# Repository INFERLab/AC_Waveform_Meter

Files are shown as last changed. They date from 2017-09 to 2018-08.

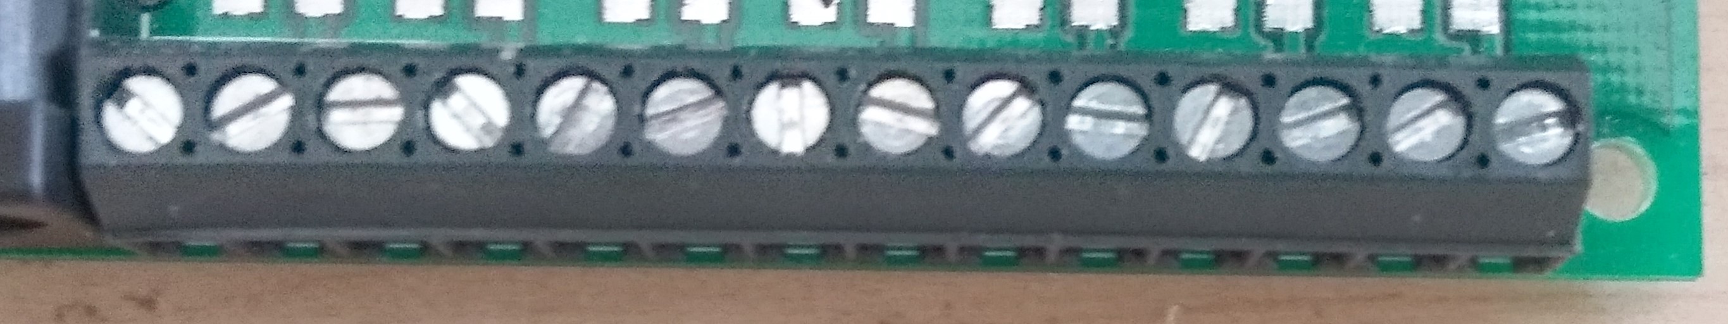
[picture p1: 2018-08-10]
images/Documentation Pictures/IMAG1642.jpg

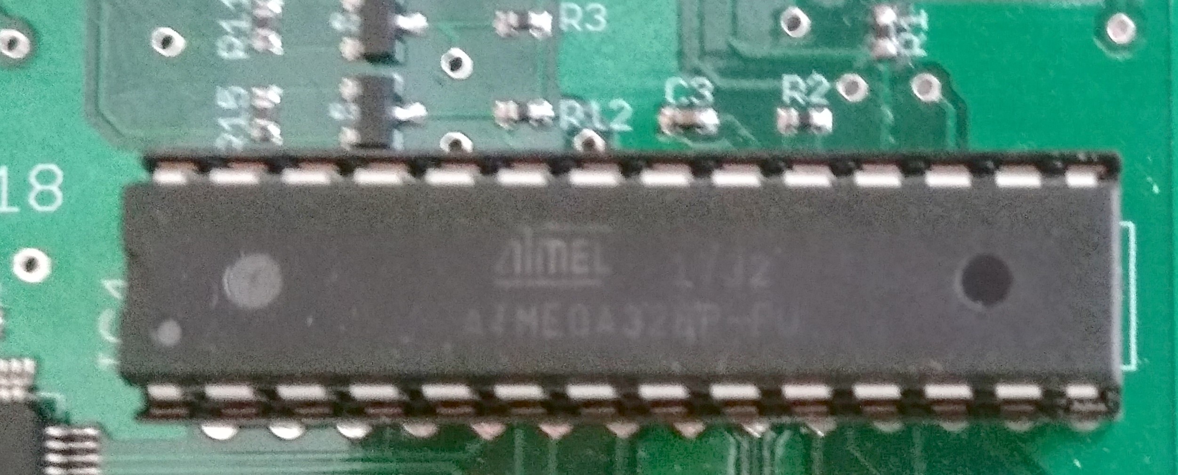
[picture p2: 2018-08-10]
images/Documentation Pictures/IMAG1639.jpg

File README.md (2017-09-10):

# AC Waveform Meter 
Arduino-based Open-source AC Waveform meter in a shield form factor for the Raspberry Pi 3. This low-cost AC power meter is designed to continuously measure voltage and current waveforms at up to 14 kHz.

## Repository Contents
- **/hardware** - All Eagle designs files (.brd, .sch)
- **/src** - Source files for the power meter and Raspberry Pi 3
- **/extras** - Additional documentation for the power meter
- **/examples** - Example sketches for the power meter in .ino (run these from the Arduino IDE) and .c

## Wiki
Set up details for the micro controller firmware and the Raspberry Pi 3.

## Version History
- V1.0 - Initial Release

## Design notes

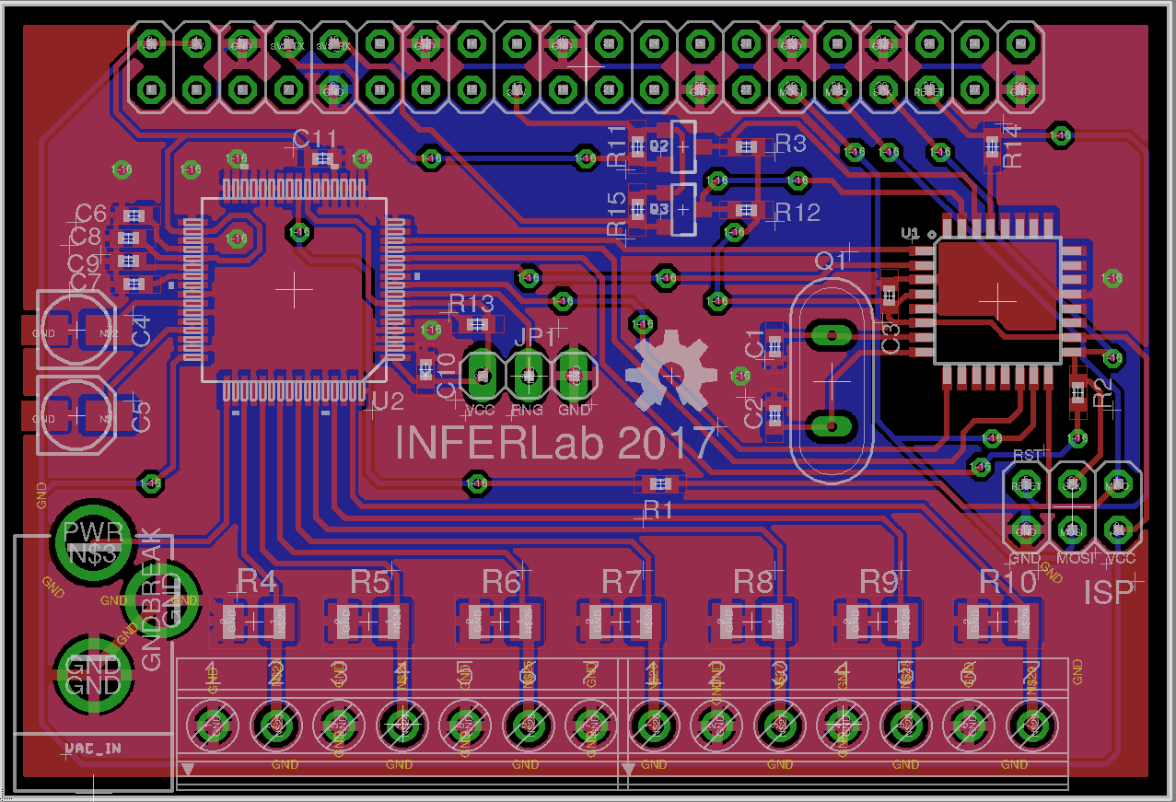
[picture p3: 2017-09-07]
hardware/EaglePCB.png

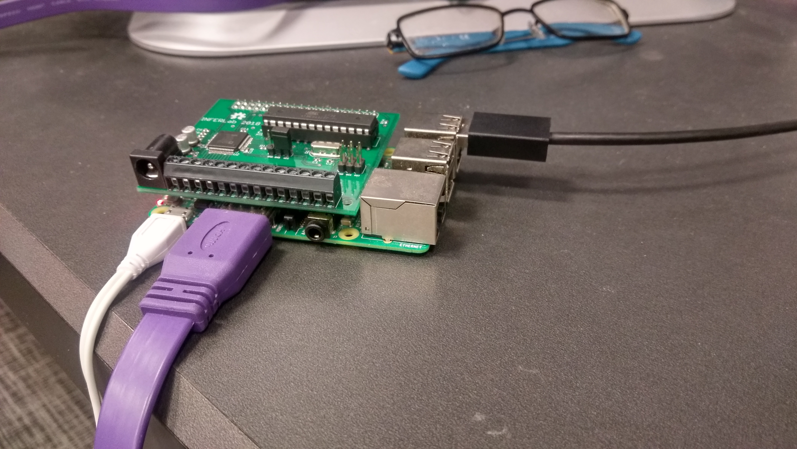
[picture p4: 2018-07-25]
images/Documentation Pictures/IMAG1631.jpg

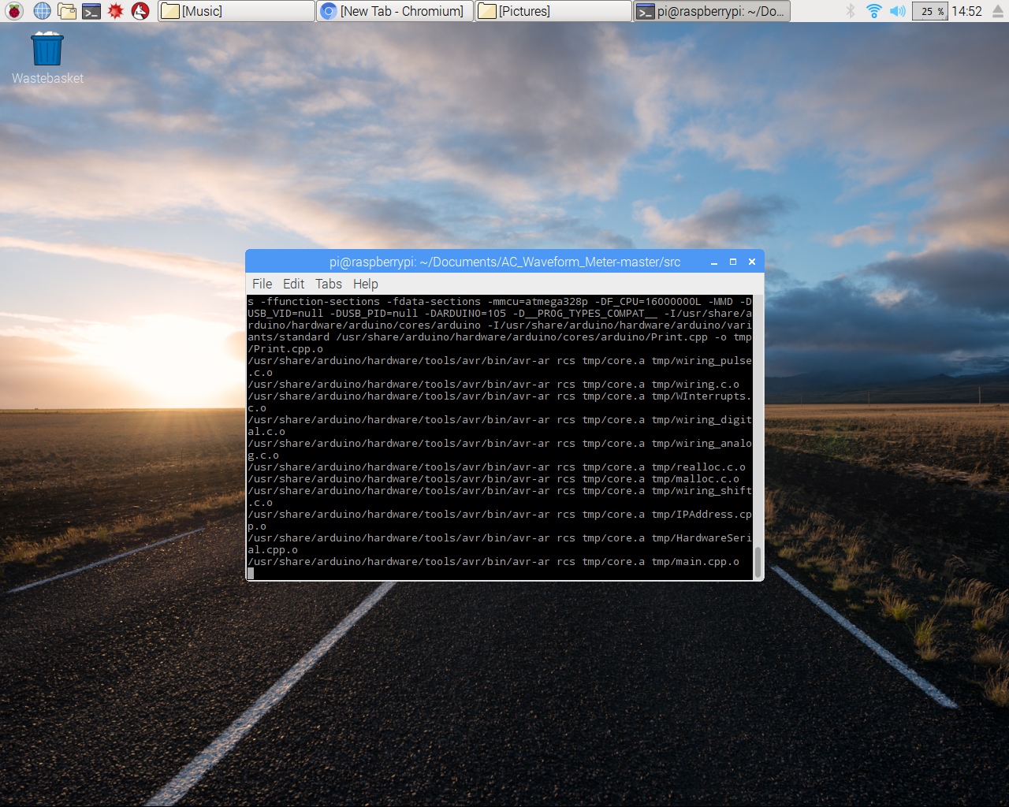
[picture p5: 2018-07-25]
images/Documentation Pictures/2018-07-11-145228_1280x1024_scrot.png

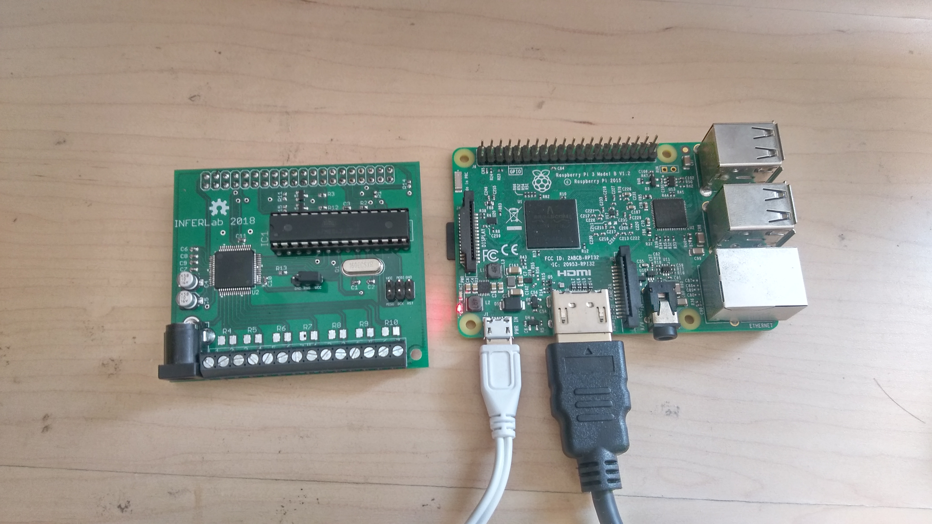
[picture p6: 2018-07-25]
images/Documentation Pictures/IMAG1637.jpg

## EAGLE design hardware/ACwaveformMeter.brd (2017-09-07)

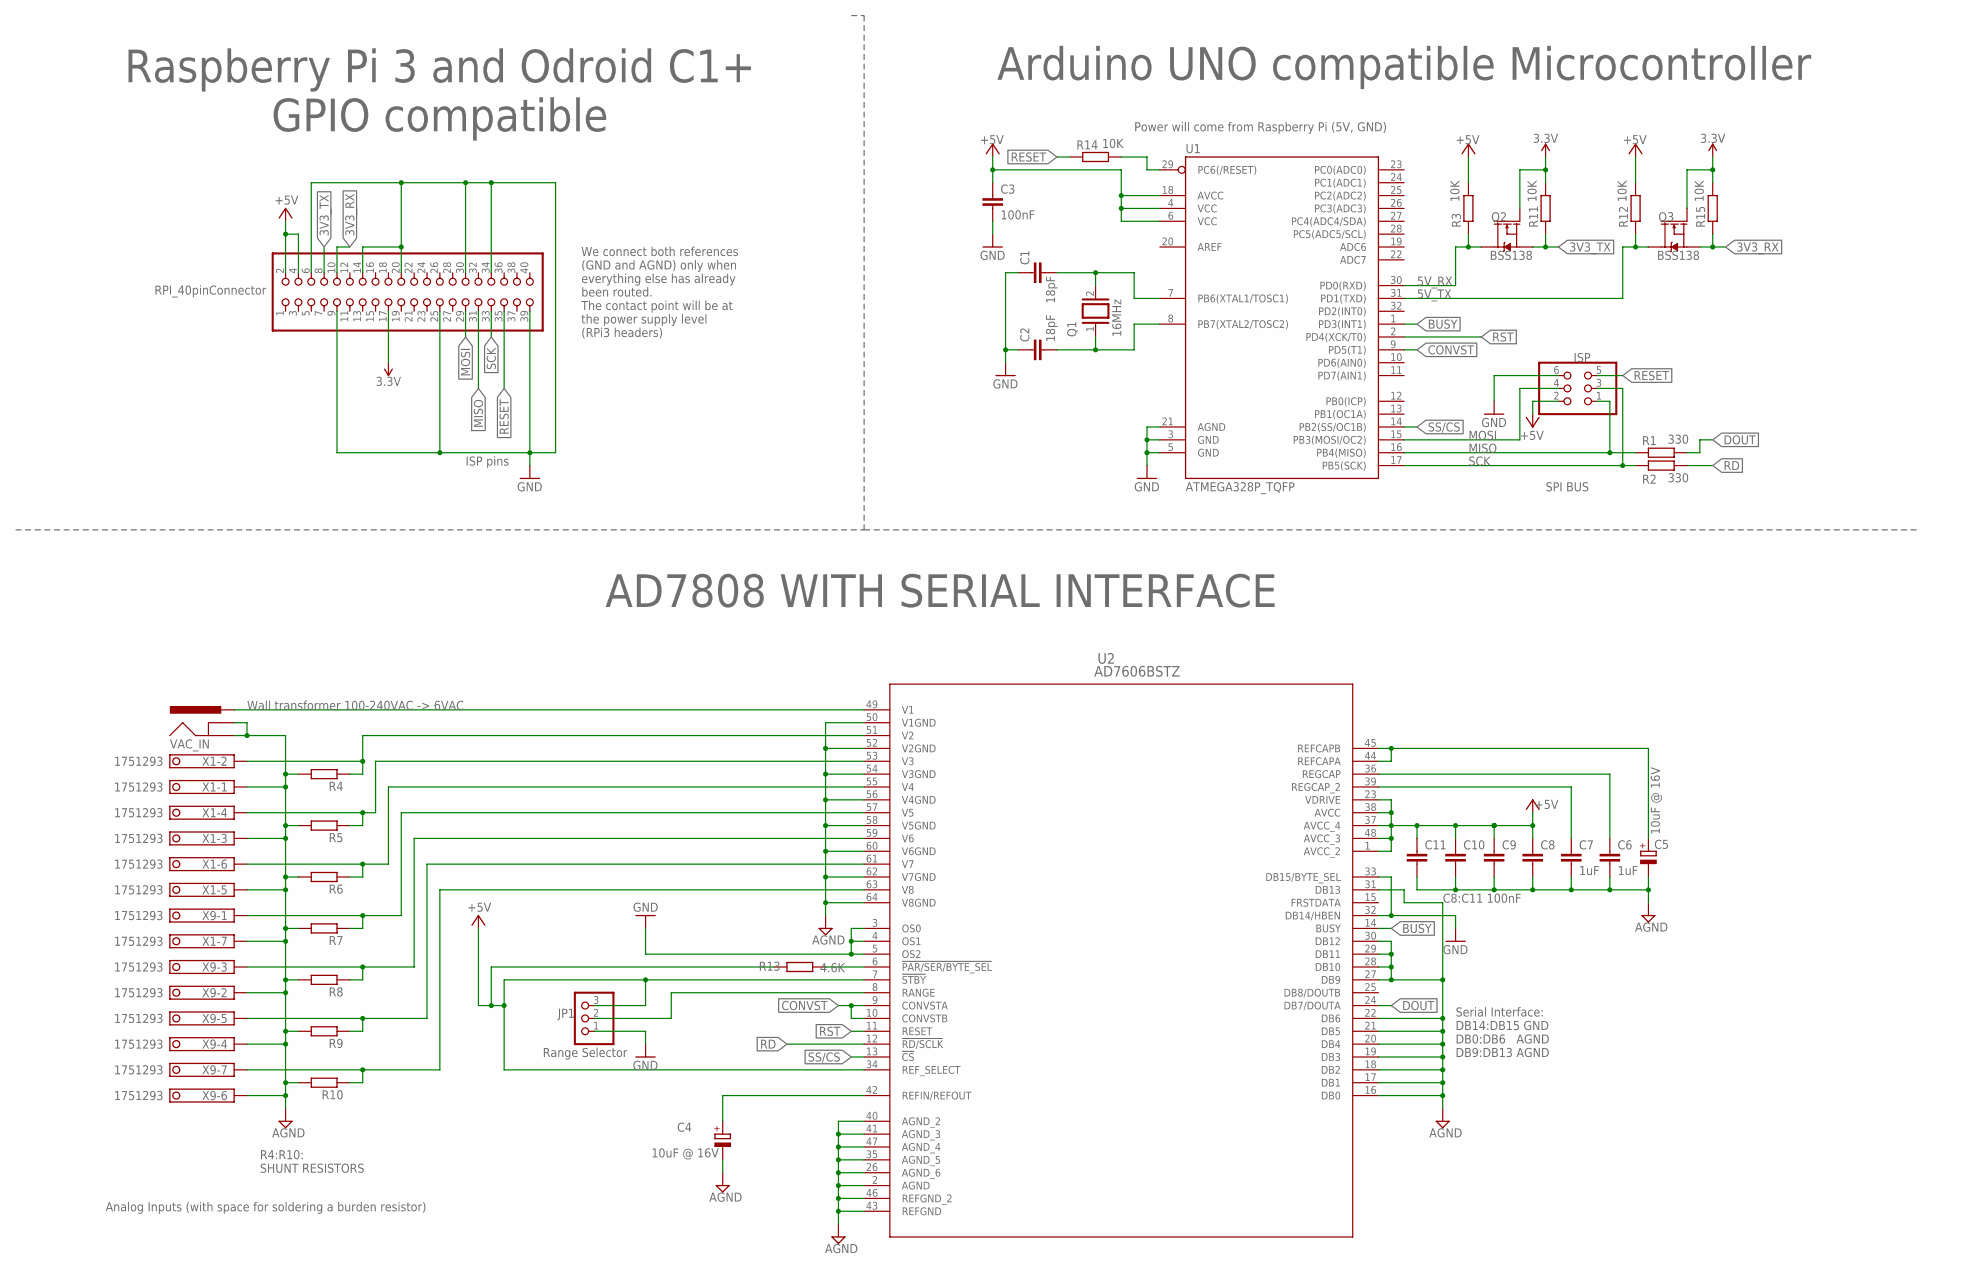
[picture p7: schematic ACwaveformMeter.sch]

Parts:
C1, C2: 18pF; C0402
C3, C8, C9, C10, C11: 100nF; C0402
C4, C5: 10uF @ 16V; 153CLV-0405
C6, C7: 1uF; C0402
ISP: ISP6pin; 2X03
JP1: PINHD-1X3; 1X03
Q1: 16MHz; QS
Q2, Q3: BSS138; SOT23-3
R1, R2: 330; R0402
R3, R11, R12, R14, R15: 10K; R0402
R4, R5, R6, R7, R8, R9, R10: R-EU_M1206; M1206
R13: 4.6K; R0402
RASPBERRY_PI3: RPI_40pinConnector; 2X20
U1: ATMEGA328P_TQFP; TQFP32-08
U2: AD7606BSTZ; ST_64_2
VAC_IN: POWER_JACKPTH_LOCK; POWER_JACK_PTH_LOCK
X1, X9: 1751293

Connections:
3.3V: Q2.1 (G), Q3.1 (G), R11.2, R15.2, RASPBERRY_PI3.17
3V3_RX: Q3.2 (S), R15.1, RASPBERRY_PI3.10
3V3_TX: Q2.2 (S), R11.1, RASPBERRY_PI3.8
5V_RX: Q2.3 (D), R3.1, U1.30 (PD0(RXD))
5V_TX: Q3.3 (D), R12.1, U1.31 (PD1(TXD))
+5V: C3.1, C8.1, C9.1, C10.1, C11.1, ISP.2, JP1.3, R3.2, R12.2, R13.1, RASPBERRY_PI3.2, RASPBERRY_PI3.4, U1.4 (VCC), U1.6 (VCC), U1.18 (AVCC), U2.1 (AVCC_2), U2.7 (!STBY), U2.23 (VDRIVE), U2.34 (REF_SELECT), U2.37 (AVCC_4), U2.38 (AVCC), U2.48 (AVCC_3)
BUSY: U1.1 (PD3(INT1)), U2.14 (BUSY)
CONVST: U1.9 (PD5(T1)), U2.9 (CONVSTA), U2.10 (CONVSTB)
DOUT: R1.2, U2.24 (DB7/DOUTA)
GND: C1.1, C2.1, C3.2, C4.-, C5.-, C6.2, C7.2, C8.2, C9.2, C10.2, C11.2, ISP.6, JP1.1, R4.2, R5.2, R6.2, R7.2, R8.2, R9.2, R10.2, RASPBERRY_PI3.6, RASPBERRY_PI3.9, RASPBERRY_PI3.14, RASPBERRY_PI3.20, RASPBERRY_PI3.25, RASPBERRY_PI3.30, RASPBERRY_PI3.34, RASPBERRY_PI3.39, U1.3 (GND), U1.5 (GND), U1.21 (AGND), U2.2 (AGND), U2.3 (OS0), U2.4 (OS1), U2.5 (OS2), U2.16 (DB0), U2.17 (DB1), U2.18 (DB2), U2.19 (DB3), U2.20 (DB4), U2.21 (DB5), U2.22 (DB6), U2.26 (AGND_6), U2.27 (DB9), U2.28 (DB10), U2.29 (DB11), U2.30 (DB12), U2.31 (DB13), U2.32 (DB14/HBEN), U2.33 (DB15/BYTE_SEL), U2.35 (AGND_5), U2.40 (AGND_2), U2.41 (AGND_3), U2.43 (REFGND), U2.46 (REFGND_2), U2.47 (AGND_4), U2.50 (V1GND), U2.52 (V2GND), U2.54 (V3GND), U2.56 (V4GND), U2.58 (V5GND), U2.60 (V6GND), U2.62 (V7GND), U2.64 (V8GND), VAC_IN.GND, VAC_IN.GNDBREAK, X1.1, X1.3, X1.5, X1.7, X9.2, X9.4, X9.6
MISO: ISP.1, R1.1, RASPBERRY_PI3.31, U1.16 (PB4(MISO))
MOSI: ISP.4, RASPBERRY_PI3.29, U1.15 (PB3(MOSI/OC2))
unnamed: C5.+, U2.44 (REFCAPA), U2.45 (REFCAPB)
unnamed: C4.+, U2.42 (REFIN/REFOUT)
unnamed: U2.49 (V1), VAC_IN.PWR
unnamed: C6.1, U2.36 (REGCAP)
unnamed: C7.1, U2.39 (REGCAP_2)
unnamed: C1.2, Q1.2, U1.7 (PB6(XTAL1/TOSC1))
unnamed: C2.2, Q1.1, U1.8 (PB7(XTAL2/TOSC2))
unnamed: R14.2, U1.29 (PC6(/RESET))
unnamed: JP1.2, U2.8 (RANGE)
unnamed: R13.2, U2.6 (!PAR/SER/BYTE_SEL)
unnamed: R4.1, U2.51 (V2), X1.2
unnamed: R5.1, U2.53 (V3), X1.4
unnamed: R6.1, U2.55 (V4), X1.6
unnamed: R7.1, U2.57 (V5), X9.1
unnamed: R8.1, U2.59 (V6), X9.3
unnamed: R9.1, U2.61 (V7), X9.5
unnamed: R10.1, U2.63 (V8), X9.7
RD: R2.2, U2.12 (!RD/SCLK)
RESET: ISP.5, R14.1, RASPBERRY_PI3.35
RST: U1.2 (PD4(XCK/T0)), U2.11 (RESET)
SCK: ISP.3, R2.1, RASPBERRY_PI3.33, U1.17 (PB5(SCK))
SS/CS: U1.14 (PB2(SS/OC1B)), U2.13 (!CS)

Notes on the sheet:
Power will come from Raspberry Pi (5V, GND)
SPI BUS
Analog Inputs (with space for soldering a burden resistor)
C8:C11 100nF
Serial Interface: DB14:DB15 GND DB0:DB6 AGND DB9:DB13 AGND
We connect both references (GND and AGND) only when everything else has already been routed. The contact point will be at the power supply level (RPi3 headers)
Wall transformer 100-240VAC -> 6VAC
R4:R10: SHUNT RESISTORS
Raspberry Pi 3 and Odroid C1+ GPIO compatible
Arduino UNO compatible Microcontroller
Range Selector
AD7808 WITH SERIAL INTERFACE
ISP pins

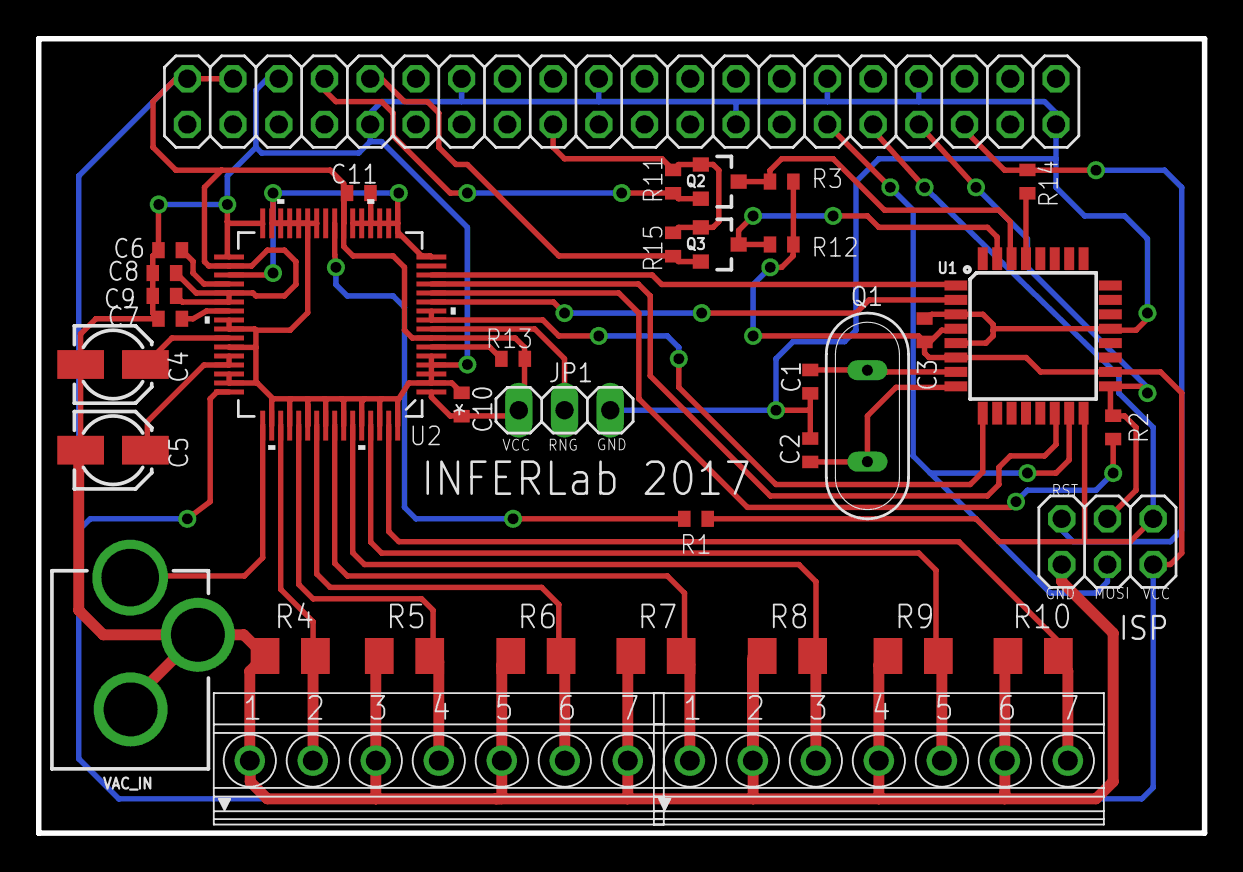
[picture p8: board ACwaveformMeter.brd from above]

Board: 2 copper layers, 64.8 x 44.1 mm, 37 parts (0 on the bottom side), 34 nets.

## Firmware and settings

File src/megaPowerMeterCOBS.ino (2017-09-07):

#include <SPI.h>

#define FOSC 16000000 // Clock speed
#define BAUD 2000000 // 2Mbps
#define MYUBRR 0 //FOSC/8/BAUD -1
// for COBS implementation
#define FinishBlock(X) (*code_ptr = (X), code_ptr = dst++, code = 0x01)   

/** Pin mapping for ADC, Arduino UNO, Atmega328P
 *   ADC     ARDUINO UNO    Atmega328P
 *   BUSY        PIN3          PD03
 *  RESET        PIN4          PD04
 *  CONVST       PIN5          PD05
 *    CS        PIN10        PB02(SS)
 *   DB07       PIN12        PB04(MISO)
 *    RD        PIN13        PB05(SCK)
 */

// Global Variables
#define TOTAL_RAW_BYTES 16
#define MAX_CHANNELS 8 
#define NUM_CHANNELS 1

byte rawCode[TOTAL_RAW_BYTES];
byte COBSframe[TOTAL_RAW_BYTES + 1];

// for testing purposes
unsigned long timeCycle;

/**
 * setup()
 * Purpose: Port state definition and initial values
 */
void setup() {
    // Output: PD05/CONVST, PD04/RESET
    // Input: PD03/BUSY
    DDRD |= 0b00110000;
                
    // Output: PB05(SCK)/RD, PB02(SS)/CS
    // Input: PB04(MISO)/DB07
    DDRB |= 0b00100100;
    
    // For external serial communication (e.g. PC, Raspberry Pi)
    USART_Init(MYUBRR);
          
    /**
     * Enable SPI, set as Master
     * Prescaler: Fosc/2
     * MSB first (that's how the ADC operates)
     * SPI Mode 2 (Sample Falling, Setup Rising)
     */
    SPCR = (1 << SPE) | (1 << MSTR) | (1 << CPOL);
    SPSR |= (1 << SPI2X);

    // Set PD05/CONVST to HIGH
    PORTD |= 0b00100000;  
    // Set PB02/CS to HIGH
    PORTB |= 0b00000100;
    // Set PD04/RESET to HIGH
    PORTD |= 0b00010000;  
    delayMicroseconds(1);
    // Set PD04/RESET to LOW
    PORTD &= 0b11101111;
}

/**
 * loop()
 * Purpose: infinite loop to sample data with the ADC
 */
void loop() {    
    // Set PD05/CONVST to LOW
    PORTD &= 0b11011111;
    delayMicroseconds(10);

    // Set PD05/CONVST to HIGH
    PORTD |= 0b00100000;
 
    // for debugging purposes
    timeCycle = millis();

    // wait for conversion to complete, if BUSY is HIGH while conversion
    while ((PIND & 0b00001000) == 8);

    // Set PB02/CS to LOW
    PORTB &= 0b11111011;
                      
    /**
     * Read two bytes (16 bits) for each channel from the ADC, 
     * starting with the MSB and channel 1 (V1).
     * Final value of the array will be:
     * rawCode[0]   MSByte V1
     * rawCode[1]   LSByte V1
     *           ...
     * rawCode[14]  MSByte V8
     * rawCode[15]  LSByte V8
     */ 
    for(int i = 0; i < TOTAL_RAW_BYTES; i++) {
        rawCode[i] = SPI.transfer(0x00);
    }
    
    rawCode[0] = 0x00;
    rawCode[1] = 0x00;
    rawCode[2] = 0x00;
    rawCode[3] = 0x00;
    rawCode[4] = 0x00;
    rawCode[5] = 0x00;
    rawCode[6] = 0x00;
    rawCode[7] = 0x00;
    rawCode[8] = 0x00;
    rawCode[9] = 0x00;
    rawCode[10] = 0x00;
    rawCode[11] = 0x00;
    rawCode[12] = 0x00;
    rawCode[13] = 0x00;
    rawCode[14] = 0x00;
    rawCode[15] = 0x00;

    // Set PB02/CS to HIGH
    PORTB |= 0b00000100;

    // do byte stuffing using Consistent Overhead Byte Stuffing (COBS)
    StuffData(rawCode, NUM_CHANNELS * 2, COBSframe);
    for(int i = 0; i < NUM_CHANNELS * 2 + 1; i++) {
        USART_Transmit(COBSframe[i]); // output should be 0x03 0x11, 0x22, 0x02, 0x33
    }
    // Since we are using COBS, frame delimiter will be 0
    USART_Transmit(0x00);
}

/**
 * USART_Init()
 * Purpose: Initialize the microcontroller's USART with the specified
 * baud rate, converted to the UBRR (FOSC/8/BAUD -1) register value
 */
void USART_Init(unsigned int ubrr) {
    // Set baud rate
    UBRR0H = (unsigned char)(ubrr >> 8);
    UBRR0L = (unsigned char)ubrr;
    // Enable Rx and TX
    UCSR0B = (1 << RXEN0) | (1 << TXEN0);
    // Set frame format: 8 data, no parity, 1 stop bit
    // Default values for UCSR0C
    // Double speed for transmission
    UCSR0A |= (1 << U2X0);
}

/**
 * USART_Transmit
 * Purpose: Transmit serial data in an 8bit frame, 1 stop bit, no parity bit.
 */
void USART_Transmit(signed char data) {
    // Wait for empty transmit buffer
    while(!(UCSR0A & (1 << UDRE0)));
    // Put data into buffer, sends data
    UDR0 = data;
}

/*
 * StuffData byte stuffs “length” bytes of
 * data at the location pointed to by “ptr”,
 * writing the output to the location pointed
 * to by “dst”.
 */
void StuffData(const unsigned char *ptr, unsigned long length, unsigned char *dst) {
    const unsigned char *end = ptr + length;
    unsigned char *code_ptr = dst++;
    unsigned char code = 0x01;
    while (ptr < end) { 
        if (*ptr == 0) FinishBlock(code);
        else {
            *dst++ = *ptr;
            code++;
            if (code == 0xFF) FinishBlock(code);
        }
        ptr++;
    }
    FinishBlock(code);
}

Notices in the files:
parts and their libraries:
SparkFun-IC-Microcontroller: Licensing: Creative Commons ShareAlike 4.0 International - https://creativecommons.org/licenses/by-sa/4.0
